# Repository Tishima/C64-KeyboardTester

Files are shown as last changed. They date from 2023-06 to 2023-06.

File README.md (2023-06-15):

# C64 Keyboard Tester

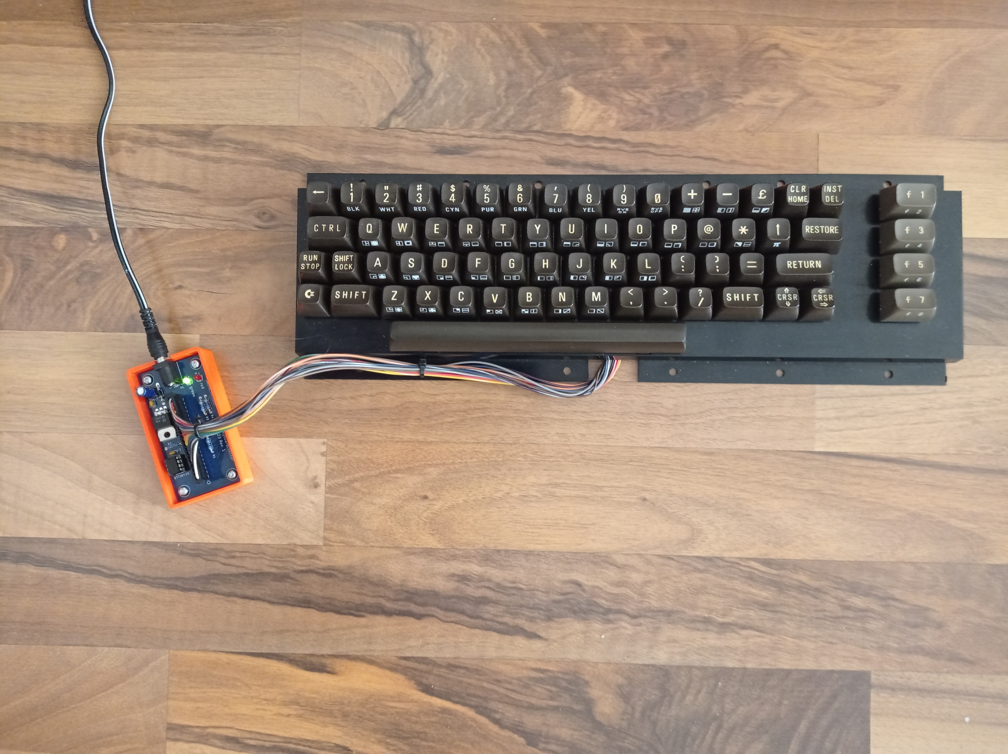
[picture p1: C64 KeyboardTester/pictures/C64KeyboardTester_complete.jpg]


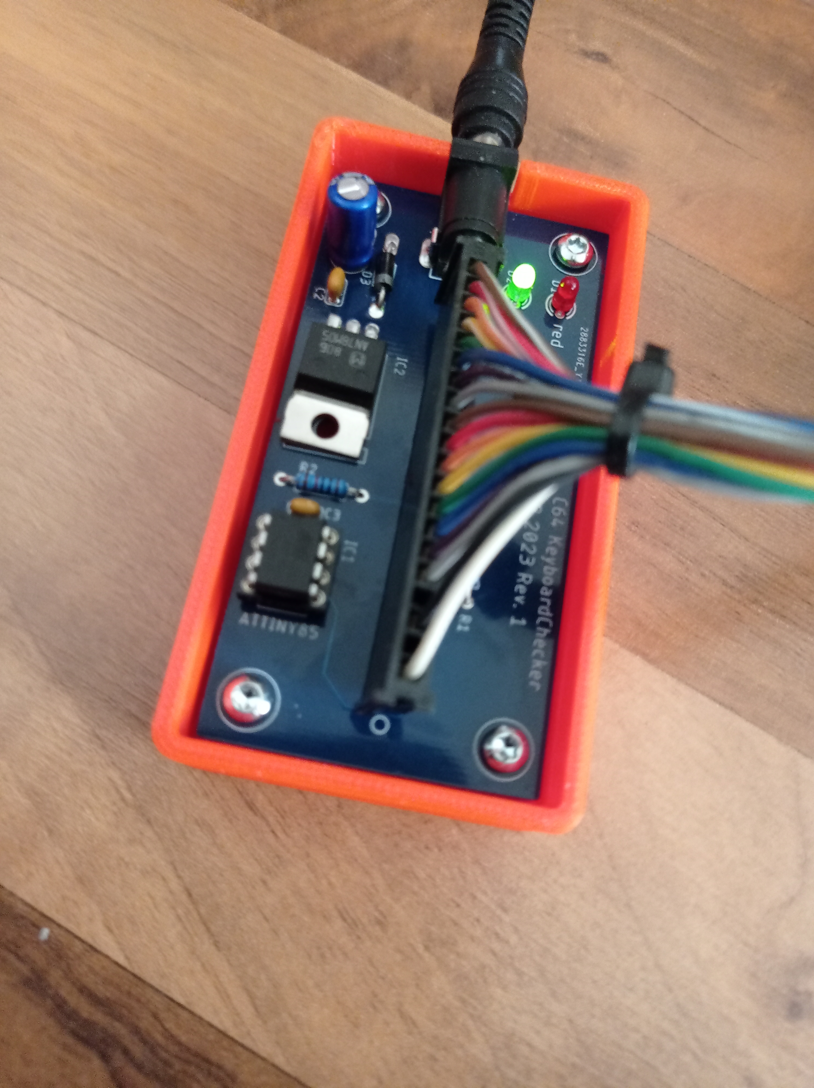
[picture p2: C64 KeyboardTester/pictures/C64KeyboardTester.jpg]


This small circuit is for testing C64 keyboards, it measure with a AVR uC ATTINY85 the resistance of a keypress.
under a treashold of 800Ohm - a red led goes on
a green led show a startet uC

so its possible to check if a key on the keyboard makes some trouble, the treshold is at 800 Ohm , a press on a C64 is mormaly detect under 1kOhm
the ATTINY85 works with internal clock at 1Mhz

This repository contains all Autodesk Eagle files, gerber file, BOM, schematics, a small Arduino source code, Hex File for ATTINY85, Projekt File for XGeco T48-3 Eprom Programmer for Firmware

STL and CAD Files for a minimal enclosure, 

Depending on where the parts and pcbs are purchased, the price for the complete circuit is around 5€ (2023), without enclosure and power supply

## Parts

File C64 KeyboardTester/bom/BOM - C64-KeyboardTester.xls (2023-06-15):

Qty | Designator | Value | Distributor | Discription | Order Number | Price | PriceTotal | Qty count | Price count
1 | IC1 | ATTINY85 | Reichelt | ATTINY 85-20 PU 8-Bit-ATtiny AVR-RISC Mikrocontroller | ATTINY 85-20 PU | 2.10 € | 2.10 € | 1 | 2.10 €
1 | IC2 | 7805T | Reichelt | L 7805 CV Spannungsregler, fest, +5 V, 1,5A, 4%, TO-220 | L 7805 CV | 0.30 € | 0.30 € | 1 | 0.30 €
1 | R1 | 1k | Reichelt | METALL 1,00K Widerstand, Metallschicht, 1,00 kOhm, 0207, 0,6 W, 1% | METALL 1,00K | 0.11 € | 0.11 € | 1 | 0.11 €
1 | R2 | 10k | Reichelt | METALL 10,0K Widerstand, Metallschicht, 10,0 kOhm, 0207, 0,6 W, 1% | METALL 10,0K | 0.11 € | 0.11 € | 1 | 0.11 €
2 | R3, R4 | 470 | Reichelt | METALL 470 Widerstand, Metallschicht, 470 Ohm, 0207, 0,6 W, 1% | METALL 470 | 0.11 € | 0.22 € | 2 | 0.22 €
1 | D1 | LED rd | Reichelt | KBT L-7104HD LED, 3 mm, bedrahtet, rot, 3 mcd, 40° | KBT L-7104HD | 0.14 € | 0.14 € | 1 | 0.14 €
1 | D2 | LED gr | Reichelt | KBT L-7104SGD LED, 3 mm, bedrahtet, grün, 40 mcd, 40° | KBT L-7104SGD | 0.16 € | 0.16 € | 1 | 0.16 €
1 | D3 | 1N4001 | Reichelt | 1N 4001 Gleichrichterdiode, 50 V, 1 A, DO-41 | 1N 4001 | 0.03 € | 0.03 € | 1 | 0.03 €
1 | X1 | CLIFF_FCR681465P | Reichelt | CLIFF FCR681465P Einbaukupplung Lötstifte | CLIFF FCR681465P | 1.15 € | 1.15 € | 1 | 1.15 €
1 | C1 | 100u | Reichelt | M-A 100U 35-2 Elko, radial, 100 µF, 35 V, RM 2,5, 85°C, 2000 h, 20% | M-A 100U 35-2 | 0.11 € | 0.11 € | 1 | 0.11 €
1 | C2, C3 | 100n | Reichelt | X7R-2,5 100N KOM Vielschicht-Kerko 100 nF, 100 V, X7R, 10 %, RM 2,5, Ammo | X7R-2,5 100N KOM | 0.05 € | 0.05 € | 1 | 0.05 €
1 | IC1_1 |  | Reichelt | GS 8P IC-Sockel, 8-polig, superflach, gedreht, vergold. | GS 8P | 0.20 € | 0.20 € | 1 | 0.20 €
1 | PSU |  | Reichelt | HNP 12-120L6 Steckernetzteil, 12 W, 12 V, 1 A | HNP 12-120L6 | 7.99 € | 7.99 € | 1 | 7.99 €
 | count | 1
 | price piece | 10.27 €
 | price total | 10.27 €

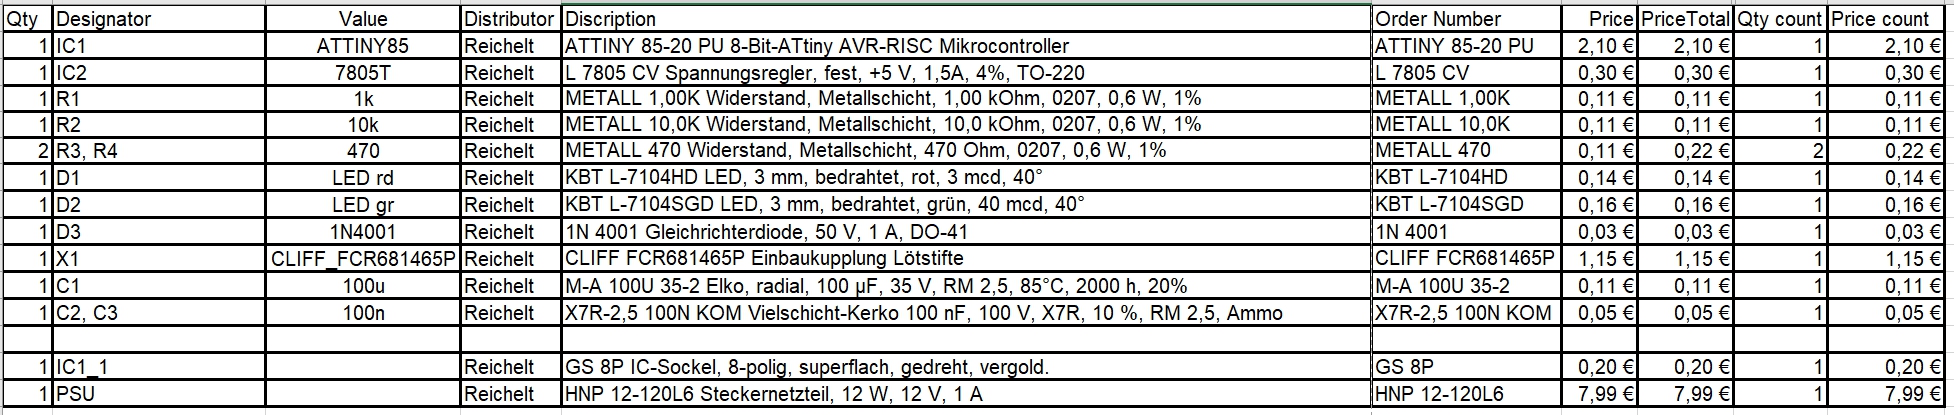
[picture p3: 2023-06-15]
C64 KeyboardTester/bom/BOM - C64-KeyboardTester.jpg

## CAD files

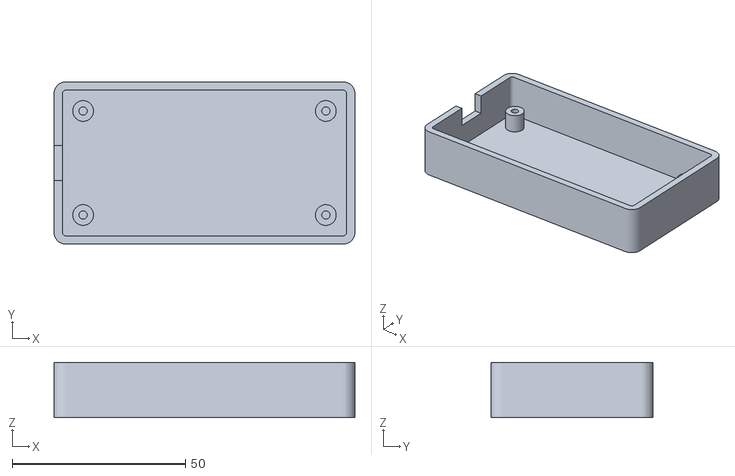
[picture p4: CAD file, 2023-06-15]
C64 KeyboardTester/STL box/C64 KeyboardTester box.stl
86.8 x 46.8 x 16.0

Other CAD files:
C64 KeyboardTester/STL box/C64 KeyboardTester box v6.f3d

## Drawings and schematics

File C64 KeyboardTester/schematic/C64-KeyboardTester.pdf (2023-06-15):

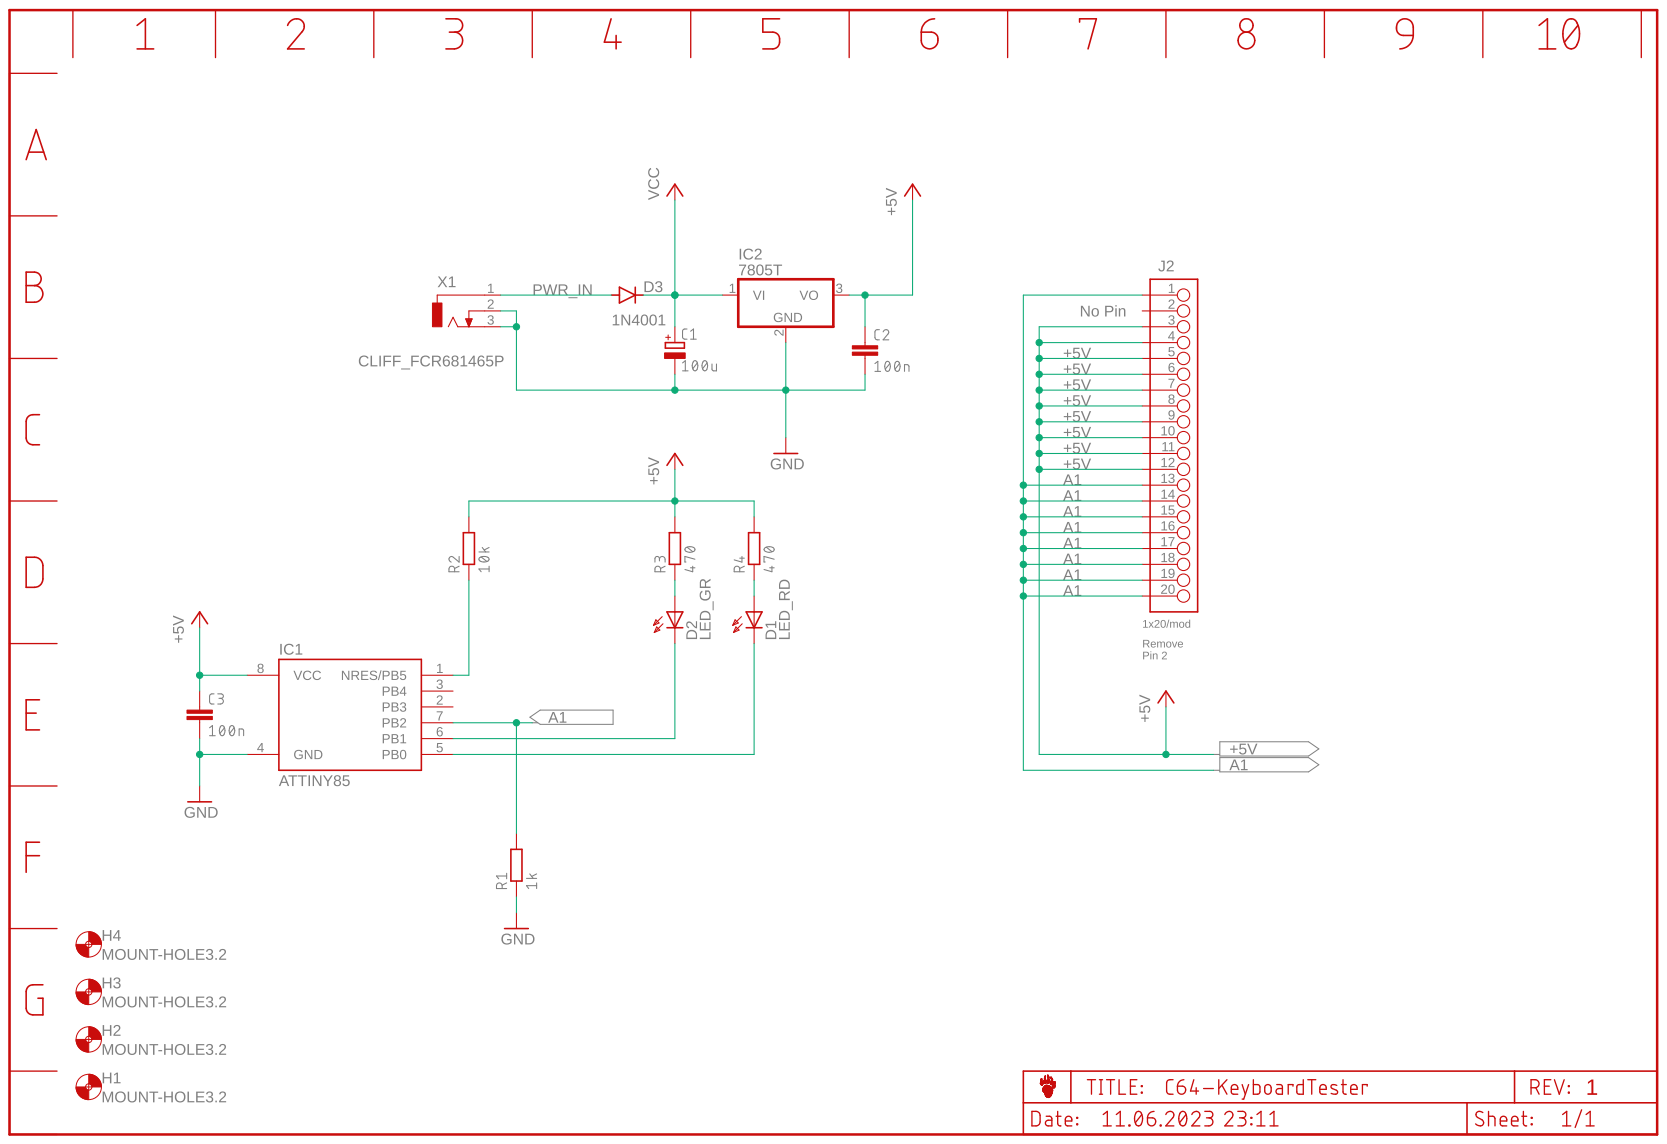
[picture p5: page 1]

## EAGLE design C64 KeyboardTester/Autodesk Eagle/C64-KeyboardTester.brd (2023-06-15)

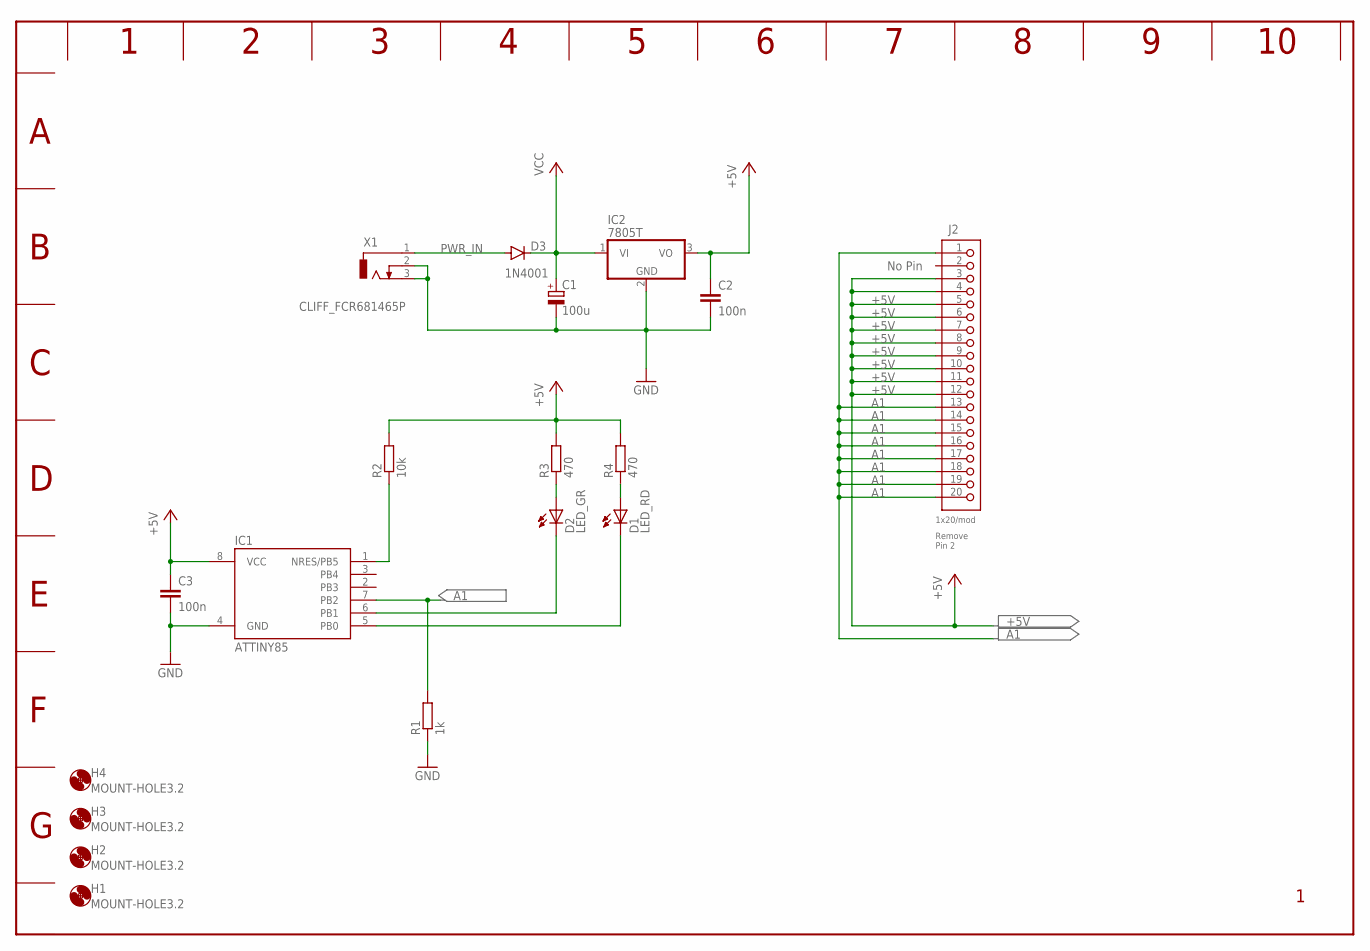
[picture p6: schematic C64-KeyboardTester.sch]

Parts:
C1: 100u; E2,5-6
C2, C3: 100n; C025-024X044
D1: LED_RD; LED3MM
D2: LED_GR; LED3MM
D3: 1N4001; DO41-10
H1, H2, H3, H4: MOUNT-HOLE3.2; 3,2
IC1: ATTINY85; PDIP08_300MIL
IC2: 7805T; TO220H
J2: 1x20/mod; 1X20
R1: 1k; 0207/10
R2: 10k; 0207/10
R3, R4: 470; 0207/10
X1: CLIFF_FCR681465P; FCR681465P

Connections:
+5V: C2.1, C3.1, IC1.8 (VCC), IC2.3 (VO), J2.3, J2.4, J2.5, J2.6, J2.7, J2.8, J2.9, J2.10, J2.11, J2.12, R2.2, R3.2, R4.2
A1: IC1.7 (PB2), J2.1, J2.13, J2.14, J2.15, J2.16, J2.17, J2.18, J2.19, J2.20, R1.2
GND: C1.-, C2.2, C3.2, IC1.4 (GND), IC2.2 (GND), R1.1, X1.2, X1.3
unnamed: D1.K (C), IC1.5 (PB0)
unnamed: D2.K (C), IC1.6 (PB1)
unnamed: IC1.1 (NRES/PB5), R2.1
unnamed: D2.A, R3.1
unnamed: D1.A, R4.1
PWR_IN: D3.A, X1.1
VCC: C1.+, D3.C, IC2.1 (VI)

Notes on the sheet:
No Pin
Remove Pin 2

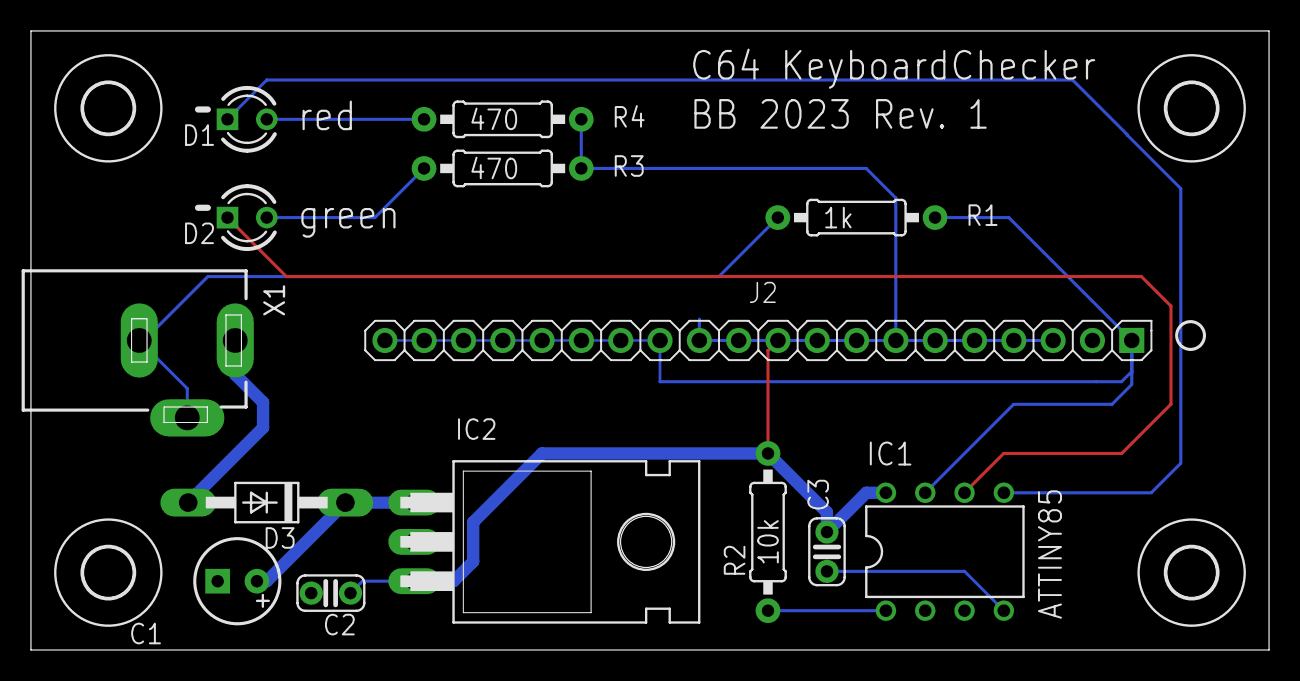
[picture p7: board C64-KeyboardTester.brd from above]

Board: 2 copper layers, 80.0 x 40.0 mm, 18 parts (0 on the bottom side), 10 nets.

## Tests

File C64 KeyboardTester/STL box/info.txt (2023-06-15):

Box Filament PETG Prusa orange

*.f3d Autodesk Fusion 360 File

4 piece screws PT 3x6mm

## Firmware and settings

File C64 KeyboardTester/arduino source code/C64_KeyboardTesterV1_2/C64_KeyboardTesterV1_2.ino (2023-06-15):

// C64 Keyboard Tester V1.2 by Bjoern Buettner
// EMail: tishima@smalltown.de
// Arduino Sketch
// MCU = ATTiny85 @ 1MHz
// this small program measure the resistance of the C64 keyboard
// and turn by a resistance under 800 OHm the red led on
// so its possible to see if the key makes some trouble

const float key_R_tresh = 800.0; // 800 Ohm key treshhold
const float R1 = 1000.0; // 1kOhm R1 resistor
const float Vin = 5.0; // 5V power supply

// under 1000 Ohm the C64 see it as a keypress
 // if it under key treshhold turn on the red led

const int raw_tresh = ((Vin / ( key_R_tresh / R1 + 1)) * 1024.0) / Vin; // calculate AD treshhold value

int analogPin = A1; //Analog Input for measure the resistance
int LED_RD = 0 ;// Red LED Key pressed
int LED_GR = 1 ;// Run PRG LED
int raw = 0;

// setup outputs
void setup(){
 pinMode(LED_RD, OUTPUT);
 pinMode(LED_GR, OUTPUT);
 digitalWrite(LED_GR, LOW); // LED GR on
}

// the loop function runs over and over again forever
void loop(){
 raw = analogRead(analogPin);   // reading analog voltage 
 
 if (raw > raw_tresh) {
   digitalWrite(LED_RD, LOW); // LED RD on
  }
   else 
  {
   digitalWrite(LED_RD, HIGH); // LED RD off
  }
 
 delay(25); // short delay
}
